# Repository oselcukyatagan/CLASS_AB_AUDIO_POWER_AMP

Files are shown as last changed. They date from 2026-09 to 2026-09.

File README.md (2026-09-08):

# CLASS_AB_AUDIO_POWER_AMP

This is the repository for the developing of the class AB audio power amplifier device. 

The repository contains the LTspice and KiCad files along with screenshots of the schematics and simulation results.

Used the technique of making a non polarized cap from 2 polarized electrolytic capacitors. to get the same capacitance, use 2 capacitors thats double the capacitance.

Vbe multiplier and the output stage transistors should be on the same heatsink for thermal considerations.

Ensured the isolated clean ground and dirty ground paths only intersect at a single point at the main power supply socket to prevent ground loops.

Adjust the vbe multiplier trimpot before initial power-on to prevent thermal runaway. calibrated quiescent current only after letting the amplifier idle to reach operating temperature.

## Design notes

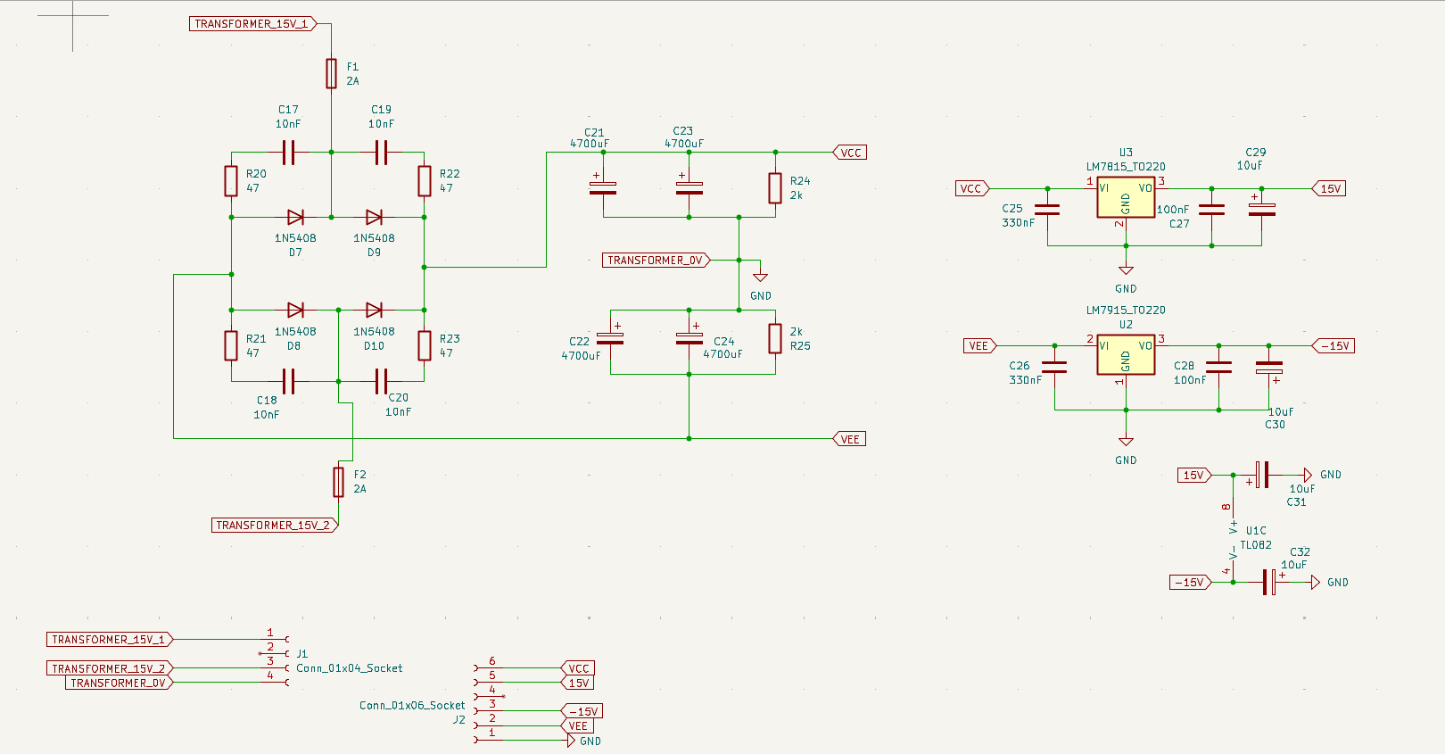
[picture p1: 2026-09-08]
KiCad_Files/kicad_psu_schematic.png

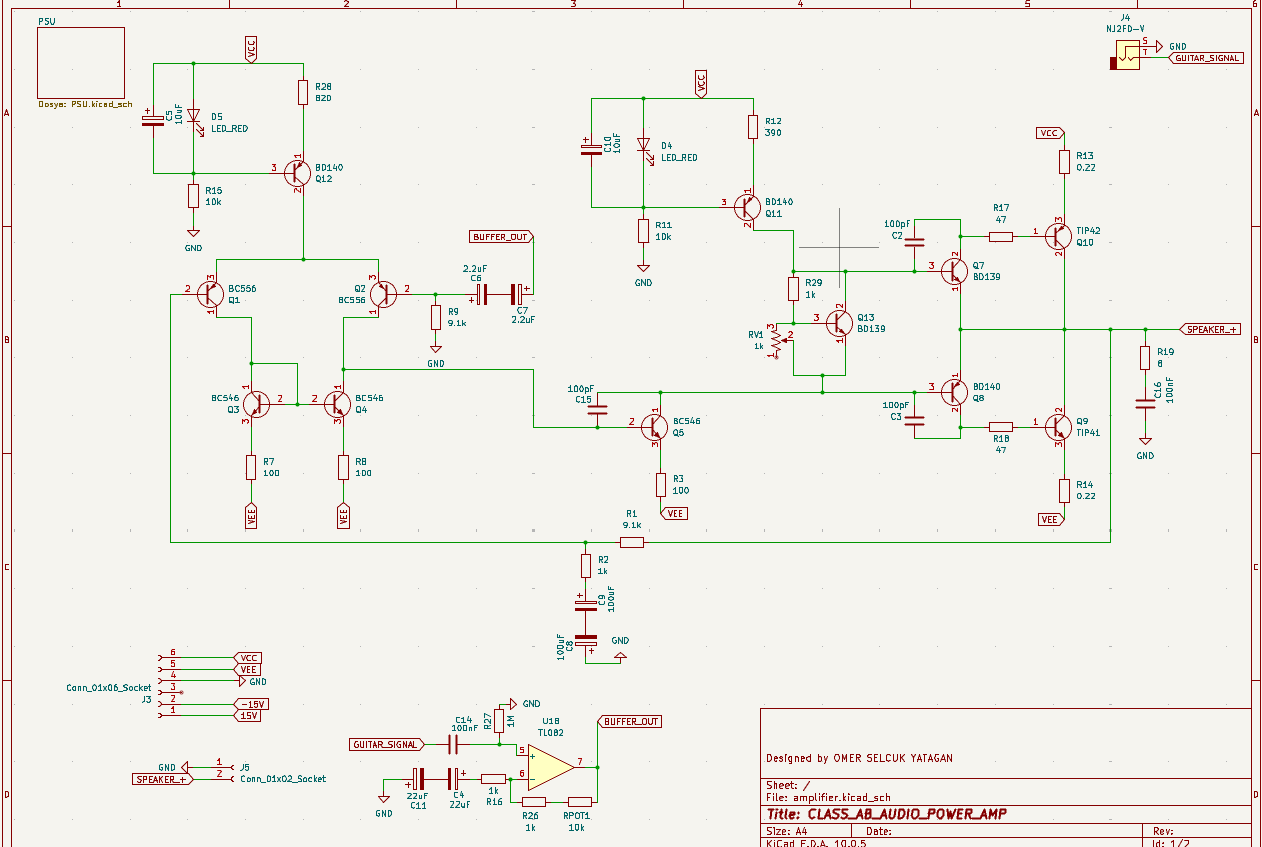
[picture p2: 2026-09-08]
KiCad_Files/kicad_amplifier_schematic.png

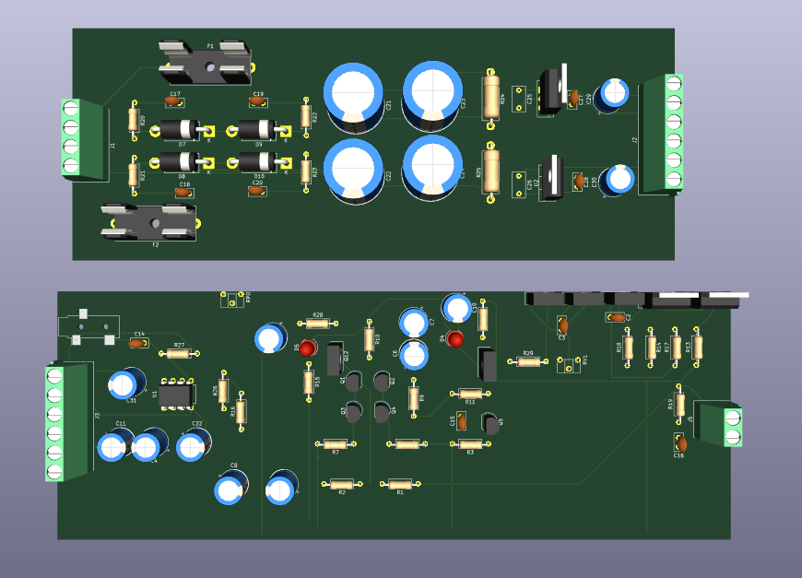
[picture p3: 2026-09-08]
KiCad_Files/kicad_pcb_3d_view.png

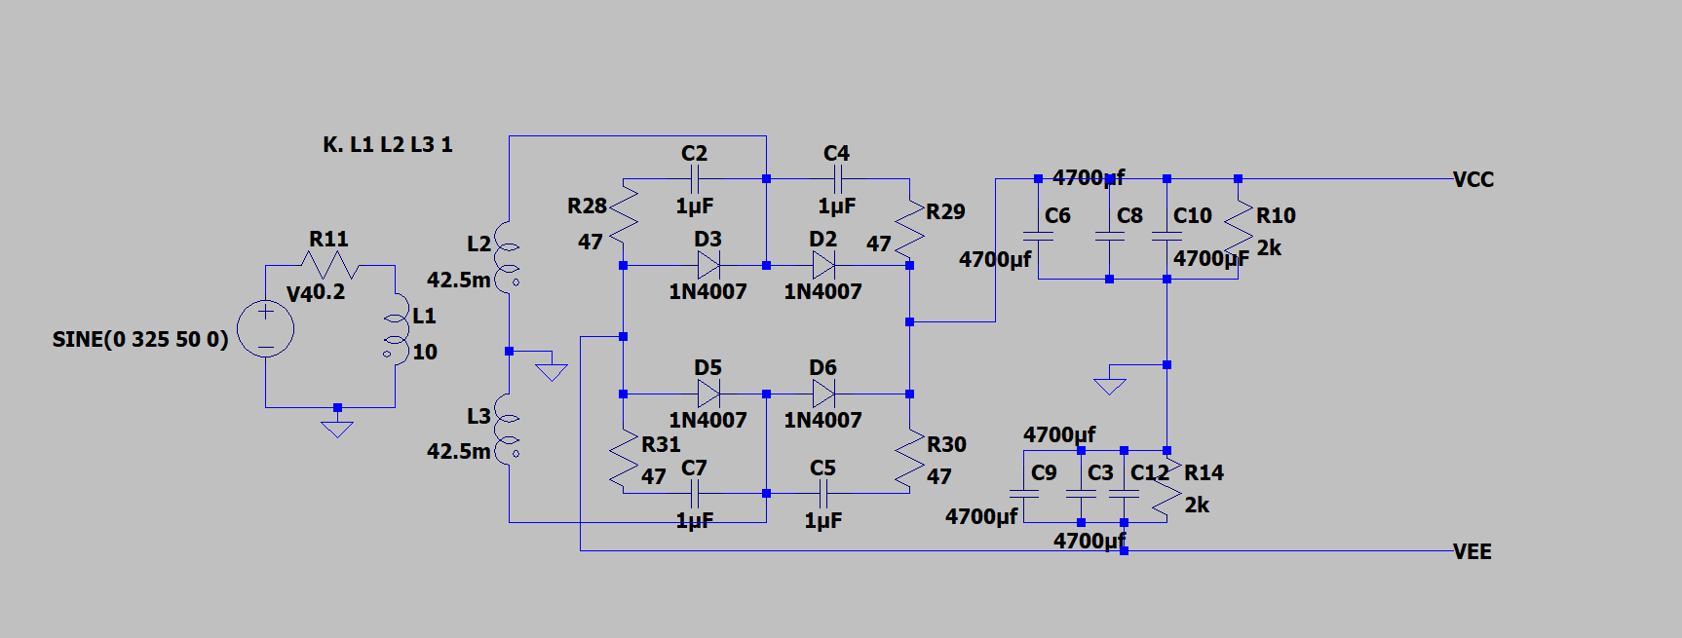
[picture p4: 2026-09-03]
LTSpice_Sim_Screenshots/PSU.png

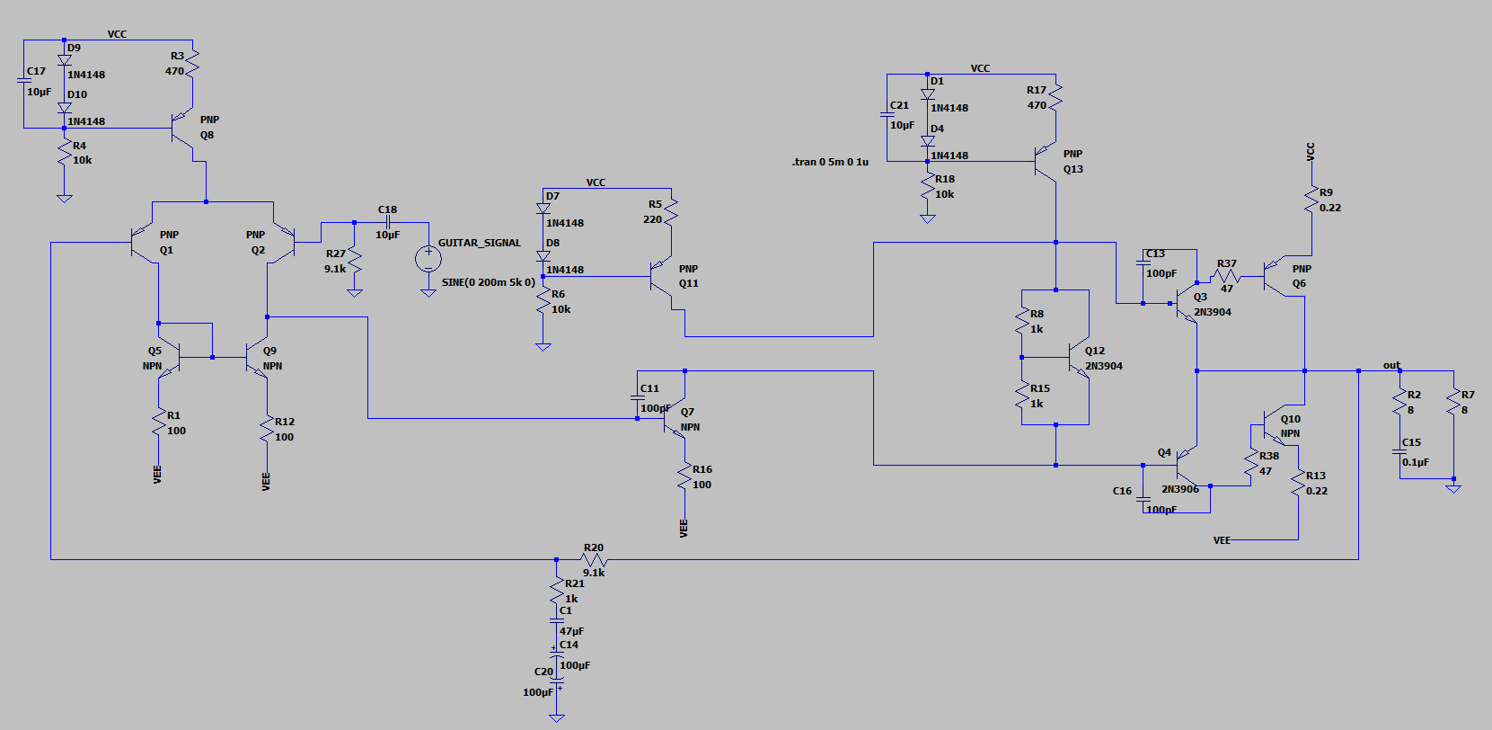
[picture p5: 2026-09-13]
LTSpice_Sim_Screenshots/amplifier_stages.png

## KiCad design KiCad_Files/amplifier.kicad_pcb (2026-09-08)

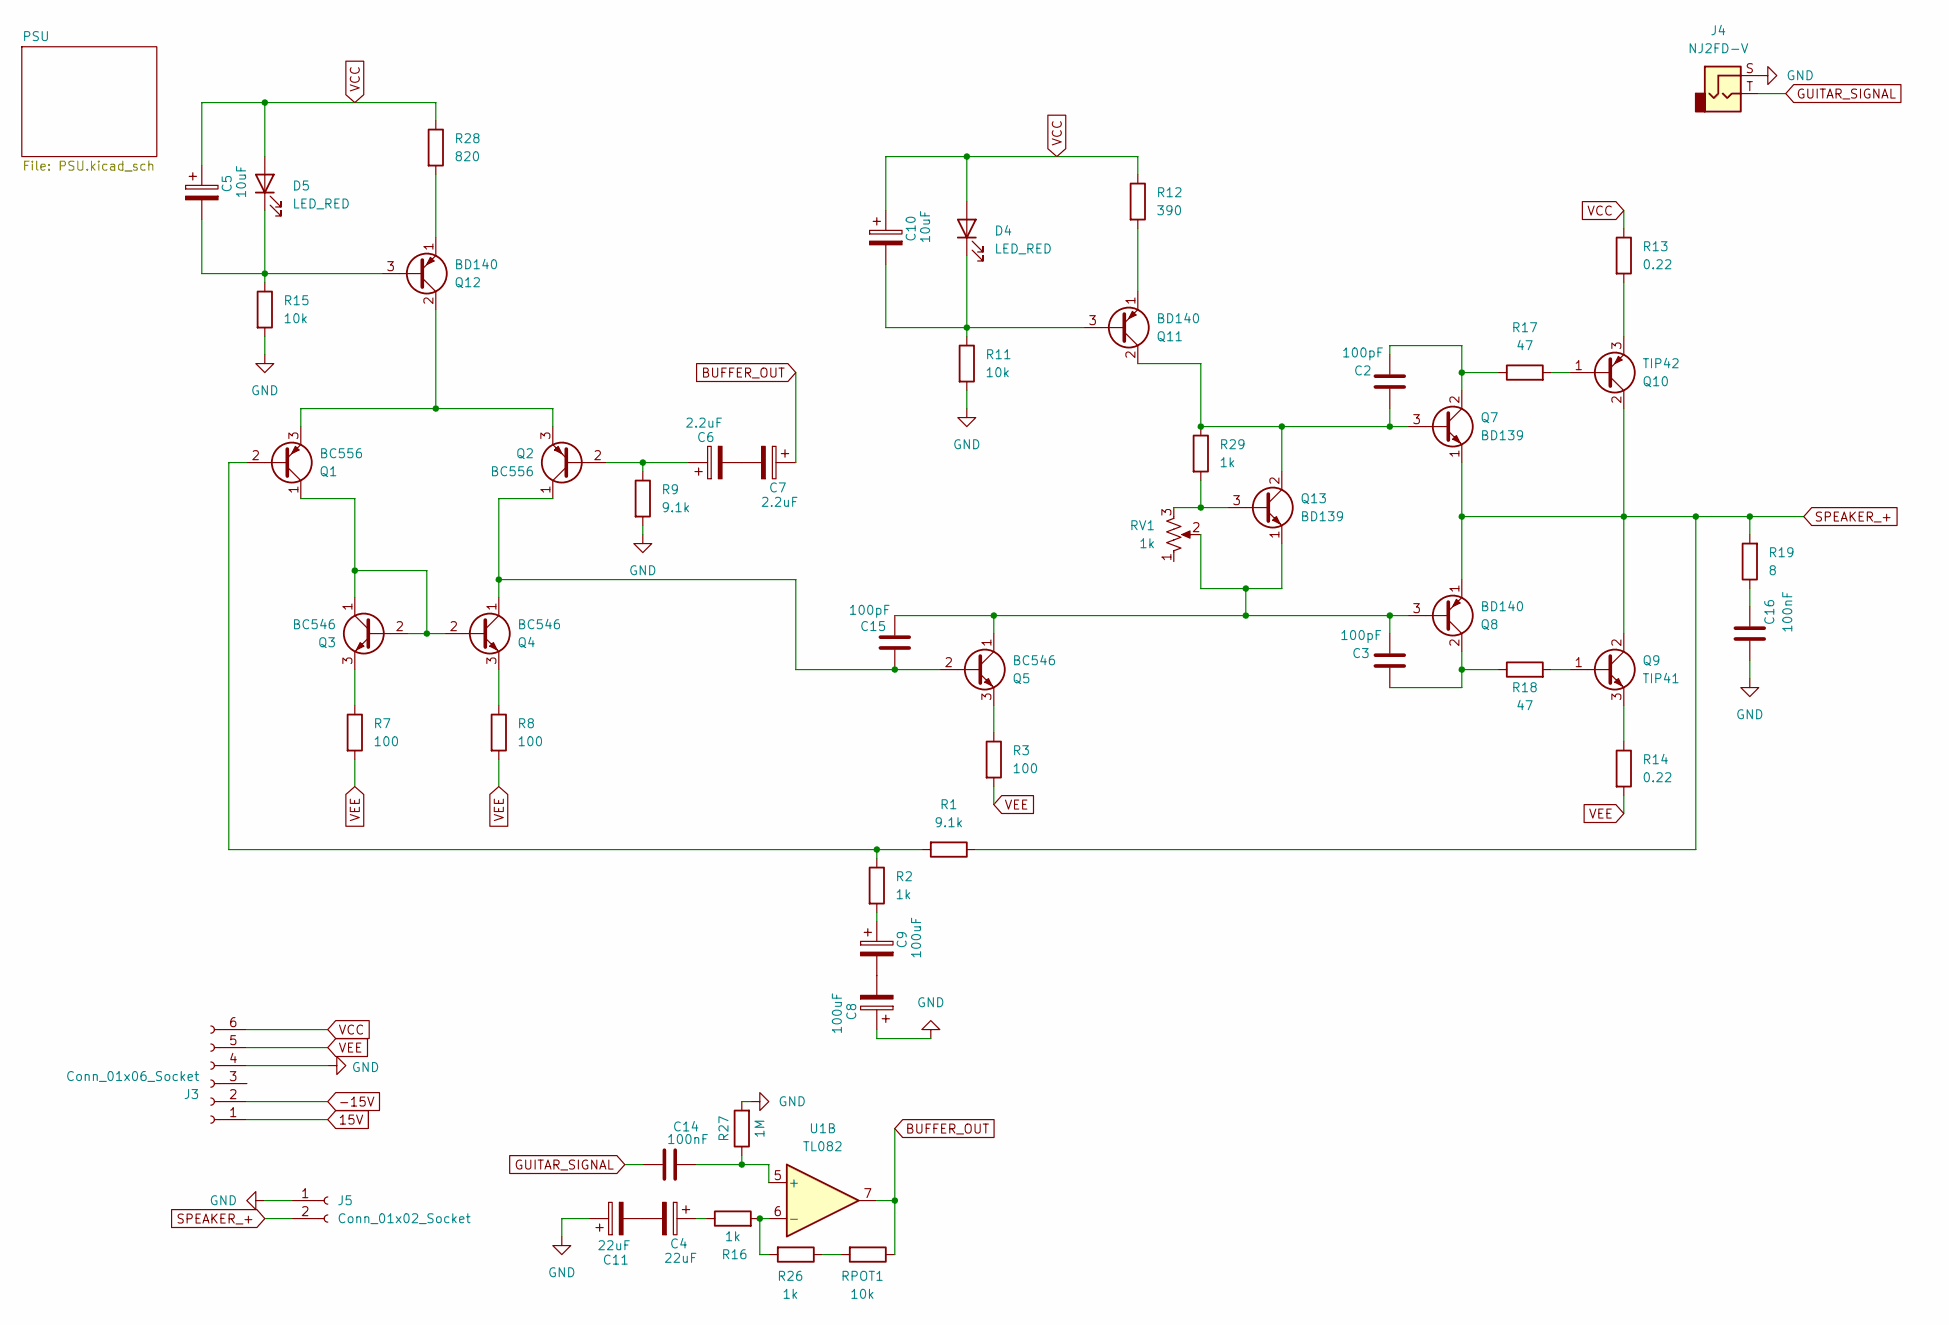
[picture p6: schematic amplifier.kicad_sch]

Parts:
C2, C3, C15: 100pF; C_Disc_D5.0mm_W2.5mm_P2.50mm
C4, C11: 22uF; CP_Radial_D8.0mm_P5.00mm
C5, C10: 10uF; CP_Radial_D8.0mm_P5.00mm
C6, C7: 2.2uF; CP_Radial_D8.0mm_P5.00mm
C8, C9: 100uF; CP_Radial_D8.0mm_P5.00mm
C14, C16: 100nF; C_Disc_D5.0mm_W2.5mm_P2.50mm
D4, D5: LED_RED; LED_D4.0mm
J3: Conn_01x06_Socket; TerminalBlock_Phoenix_MKDS-1,5-6-5.08_1x06_P5.08mm_Horizont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
J4: NJ2FD-V; Jack_3.5mm_CUI_SJ-3523-SMT_Horizontal
J5: Conn_01x02_Socket; TerminalBlock_Phoenix_MKDS-1,5-2-5.08_1x02_P5.08mm_Horizont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
Q1, Q2: BC556; TO-92_Inline
Q3, Q4, Q5: BC546; TO-92_Inline
Q7, Q13: BD139; TO-126-3_Vertical
Q8, Q11, Q12: BD140; TO-126-3_Vertical
Q9: TIP41; TO-220-3_Vertical
Q10: TIP42; TO-220-3_Vertical
R1, R9: 9.1k; R_Axial_DIN0207_L6.3mm_D2.5mm_P10.16mm_Horizontal
R2, R16, R26, R29: 1k; R_Axial_DIN0207_L6.3mm_D2.5mm_P10.16mm_Horizontal
R3, R7, R8: 100; R_Axial_DIN0207_L6.3mm_D2.5mm_P10.16mm_Horizontal
R11, R15: 10k; R_Axial_DIN0207_L6.3mm_D2.5mm_P10.16mm_Horizontal
R12: 390; R_Axial_DIN0207_L6.3mm_D2.5mm_P10.16mm_Horizontal
R13, R14: 0.22; R_Axial_DIN0207_L6.3mm_D2.5mm_P10.16mm_Horizontal
R17, R18: 47; R_Axial_DIN0207_L6.3mm_D2.5mm_P10.16mm_Horizontal
R19: 8; R_Axial_DIN0207_L6.3mm_D2.5mm_P10.16mm_Horizontal
R27: 1M; R_Axial_DIN0207_L6.3mm_D2.5mm_P10.16mm_Horizontal
R28: 820; R_Axial_DIN0207_L6.3mm_D2.5mm_P10.16mm_Horizontal
RPOT1: 10k; Potentiometer_ACP_CA6-H2,5_Horizontal
RV1: 1k; Potentiometer_ACP_CA6-H2,5_Horizontal
U1: TL082; DIP-8_W7.62mm

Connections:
15V: J3.1; also elsewhere on the board
-15V: J3.2; also elsewhere on the board
BUFFER_OUT: C7.1, RPOT1.1, U1.7
GUITAR_SIGNAL: C14.1, J4.T
unnamed: C4.1, R16.1
unnamed: C6.2, C7.2
unnamed: C8.2, C9.2
unnamed: C9.1, R2.2
unnamed: C4.2, C11.2
unnamed: C16.2, R19.1
unnamed: C10.2, D4.1 (K), Q11.3 (B), R11.1
unnamed: C5.2, D5.1 (K), Q12.3 (B), R15.1
unnamed: Q1.2 (B), R1.2, R2.1
unnamed: Q1.1 (C), Q3.1 (C), Q3.2 (B), Q4.2 (B)
unnamed 20: Q1.3 (E), Q2.3 (E), Q12.2 (C); also elsewhere on the board
unnamed: C6.1, Q2.2 (B), R9.1
unnamed: C15.1, Q2.1 (C), Q4.1 (C), Q5.2 (B)
unnamed: Q3.3 (E), R7.1
unnamed: Q4.3 (E), R8.1
unnamed: Q5.3 (E), R3.1
unnamed: C2.2, Q7.2 (C), R17.1
unnamed: C3.1, Q8.2 (C), R18.1
unnamed: Q9.1 (B), R18.2
unnamed: Q9.3 (E), R14.1
unnamed: Q10.1 (B), R17.2
unnamed: Q10.3 (E), R13.2
unnamed: C2.1, Q7.3 (B), Q11.2 (C), Q13.2 (C), R29.1
unnamed: Q11.1 (E), R12.2
unnamed: Q12.1 (E), R28.2
unnamed: Q13.3 (B), R29.2, RV1.3
unnamed: C3.2, C15.2, Q5.1 (C), Q8.3 (B), Q13.1 (E), RV1.2
unnamed: R26.1, RPOT1.2
unnamed: C14.2, R27.1, U1.5 (+)
unnamed: R16.2, R26.2, U1.6 (-)
SPEAKER_+: J5.2, Q7.1 (E), Q8.1 (E), Q9.2 (C), Q10.2 (C), R1.1, R19.2
TRANSFORMER_0V: C8.1, C11.1, C16.1, J3.4, J4.S, J5.1, R9.2, R11.2, R15.2, R27.2; also elsewhere on the board
VCC: C5.1, C10.1, D4.2 (A), D5.2 (A), J3.6, R12.1, R13.1, R28.1; also elsewhere on the board
VEE: J3.5, R3.2, R7.2, R8.2, R14.2; also elsewhere on the board

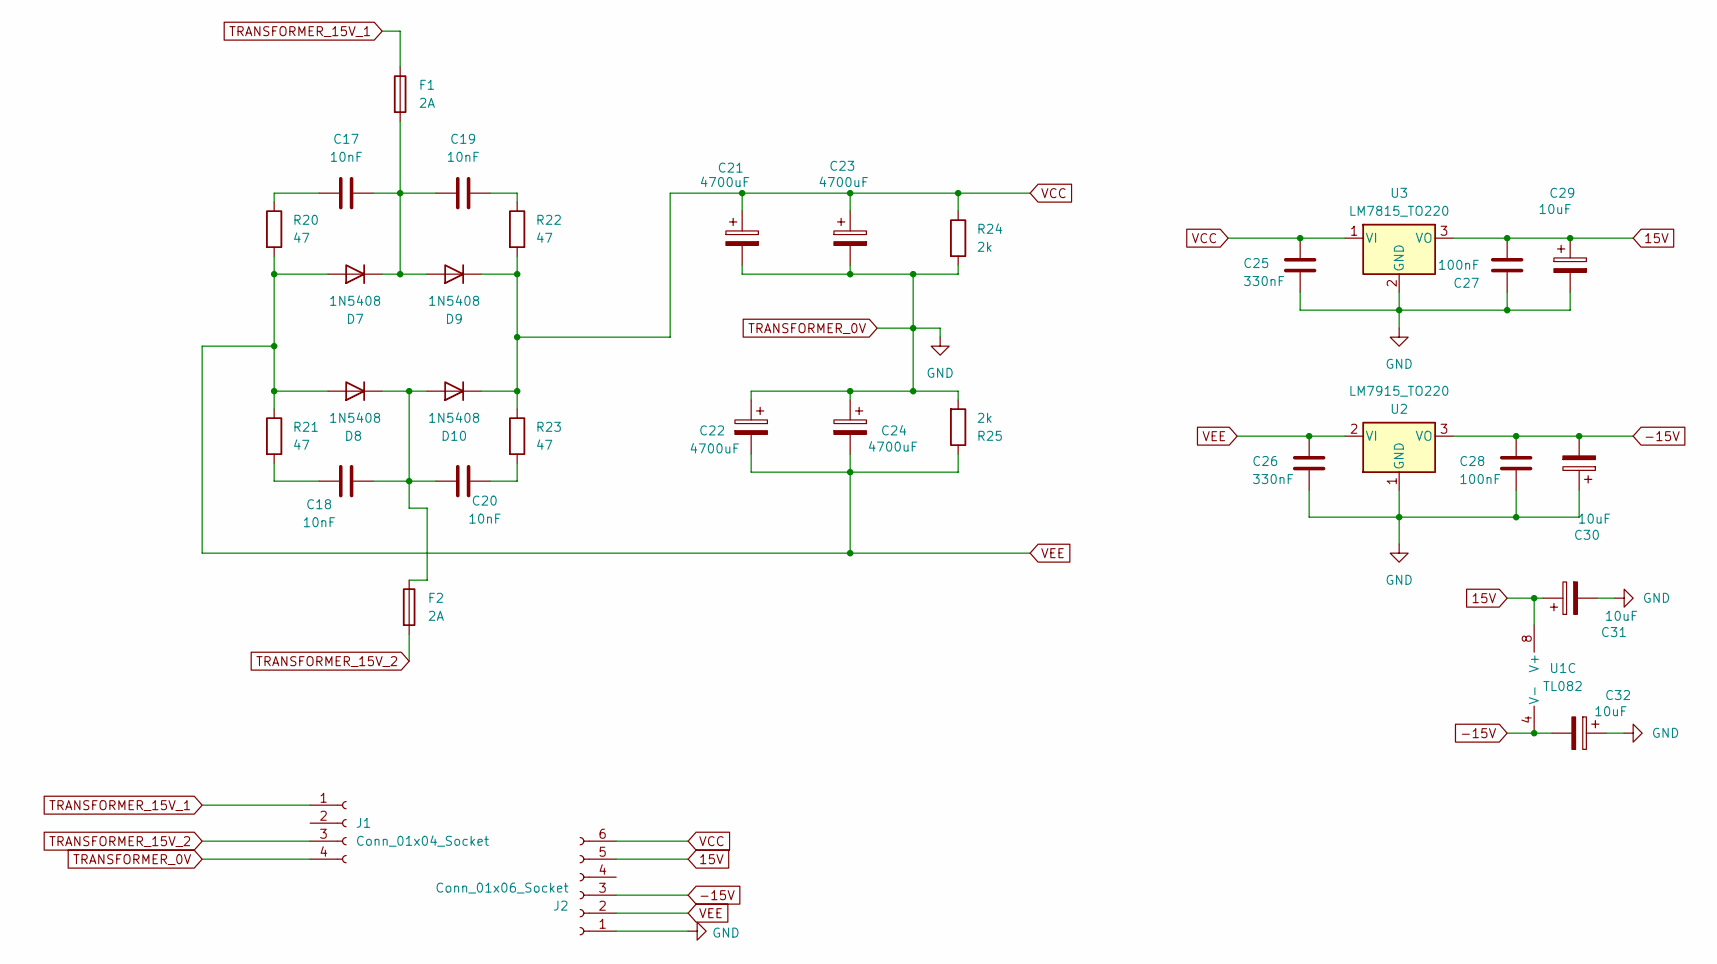
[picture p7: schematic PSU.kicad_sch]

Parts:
C17, C18, C19, C20: 10nF; C_Disc_D5.0mm_W2.5mm_P2.50mm
C21, C22, C23, C24: 4700uF; CP_Radial_D16.0mm_P7.50mm
C25, C26: 330nF; C_Rect_L7.2mm_W3.5mm_P5.00mm
C27, C28: 100nF; C_Disc_D5.0mm_W2.5mm_P2.50mm
C29, C30, C31, C32: 10uF; CP_Radial_D8.0mm_P5.00mm
D7, D8, D9, D10: 1N5408; D_DO-201AD_P15.24mm_Horizontal
F1, F2: 2A; Fuseholder_Cylinder-5x20mm_Schurter_0031_8201_Horizontal_Op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
J1: Conn_01x04_Socket; TerminalBlock_Phoenix_MKDS-1,5-4-5.08_1x04_P5.08mm_Horizont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
J2: Conn_01x06_Socket; TerminalBlock_Phoenix_MKDS-1,5-6-5.08_1x06_P5.08mm_Horizont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
R20, R21, R22, R23: 47; R_Axial_DIN0207_L6.3mm_D2.5mm_P10.16mm_Horizontal
R24, R25: 2k; R_Axial_DIN0414_L11.9mm_D4.5mm_P15.24mm_Horizontal
U1: TL082; DIP-8_W7.62mm
U2: LM7915_TO220; TO-220-3_Vertical
U3: LM7815_TO220; TO-220-3_Vertical

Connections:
15V: C27.2, C29.1, C31.1, J2.5, U1.8 (V+), U3.3 (VO); also elsewhere on the board
-15V: C28.1, C30.2, C32.2, J2.3, U1.4 (V-), U2.3 (VO); also elsewhere on the board
unnamed: C17.1, R20.1
unnamed: C18.1, R21.2
unnamed: C19.2, R22.1
unnamed: C20.2, R23.2
unnamed: C17.2, C19.1, D7.1 (K), D9.2 (A), F1.2
unnamed: C18.2, C20.1, D8.1 (K), D10.2 (A), F2.1
TRANSFORMER_0V: C21.2, C22.1, C23.2, C24.1, C25.2, C26.2, C27.1, C28.2, C29.2, C30.1, C31.2, C32.1, J1.4, J2.1, R24.2, R25.2, U2.1 (GND), U3.2 (GND); also elsewhere on the board
TRANSFORMER_15V_1: F1.1, J1.1
TRANSFORMER_15V_2: F2.2, J1.3
VCC: C21.1, C23.1, C25.1, D9.1 (K), D10.1 (K), J2.6, R22.2, R23.1, R24.1, U3.1 (VI); also elsewhere on the board
VEE: C22.2, C24.2, C26.1, D7.2 (A), D8.2 (A), J2.2, R20.2, R21.1, R25.1, U2.2 (VI); also elsewhere on the board

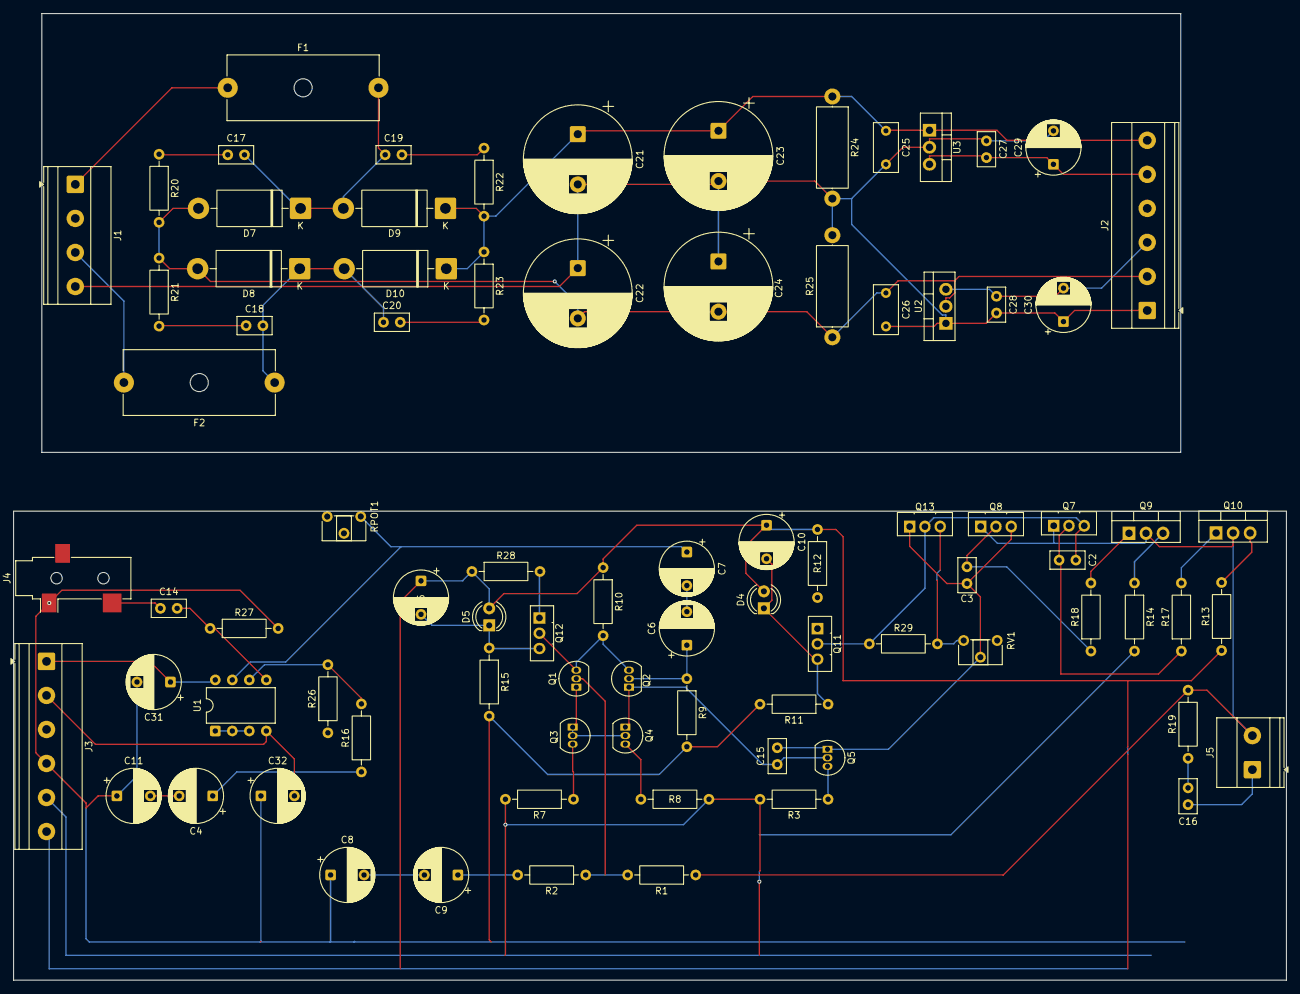
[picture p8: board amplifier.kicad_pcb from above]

Board: 2 copper layers, 190.0 x 144.3 mm, 85 parts (0 on the bottom side), 46 nets.

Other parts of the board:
R10: 10k; R_Axial_DIN0207_L6.3mm_D2.5mm_P10.16mm_Horizontal

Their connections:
unnamed 20: R10.2; also elsewhere on the board
VCC: R10.1; also elsewhere on the board

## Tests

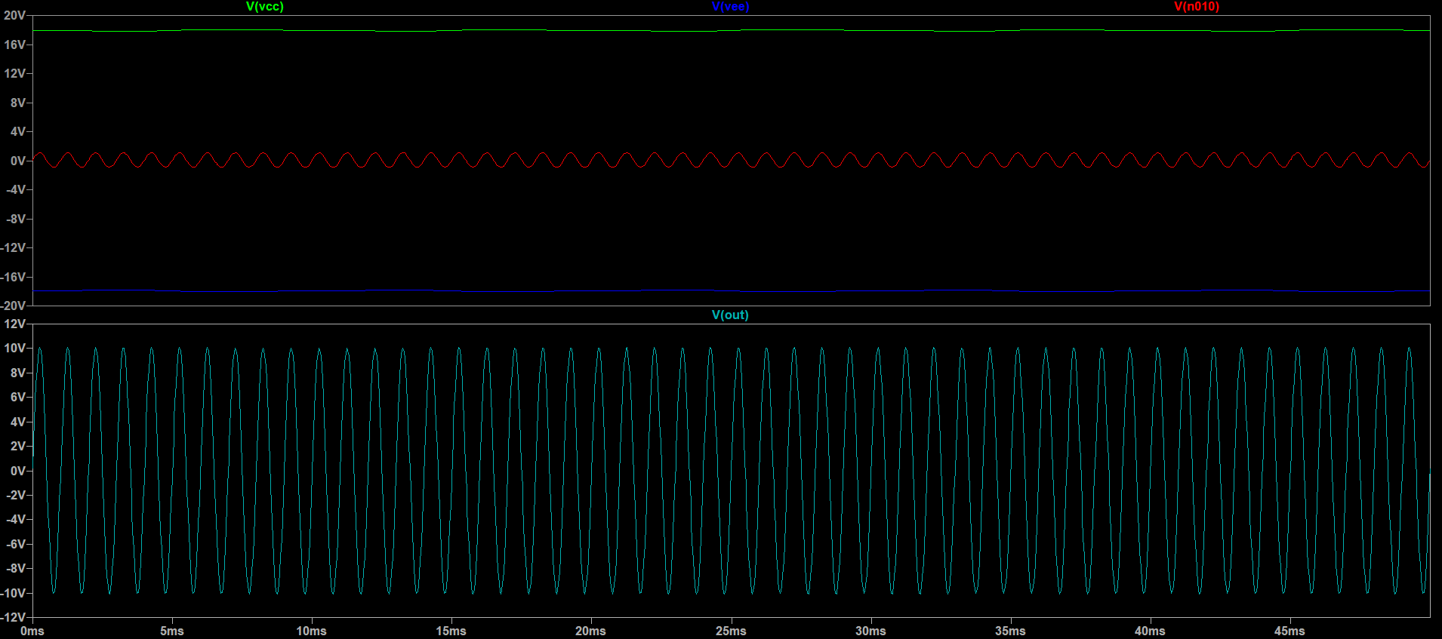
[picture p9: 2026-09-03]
LTSpice_Sim_Screenshots/simulation_result.png

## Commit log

2026-09-03 Current Progress in LTSpice
    Without the safety features. Proof of concept.
2026-09-13 updated the amplifier schematic
    added vbe multiplier and constant current source.
2026-09-13 Added ltspice schematic.
